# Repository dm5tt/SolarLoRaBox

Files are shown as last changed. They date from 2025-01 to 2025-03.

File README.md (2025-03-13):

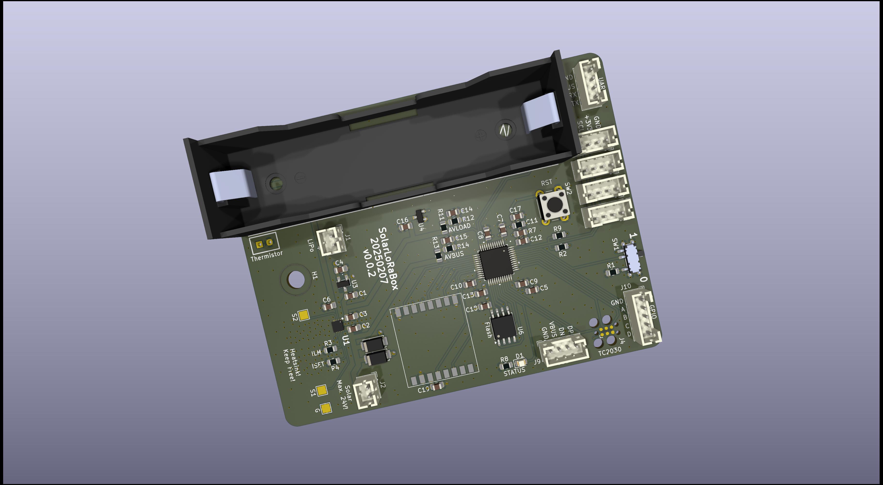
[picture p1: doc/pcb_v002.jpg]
SolarLoraBox PCB


# What is this thing?

This is an experimental platform for an solar driven LoRa sensor station based on the

- Microcontroller: ST STM32U083CCT6
- Radio: Heltec HT-RA62 (Semtech SX1262)
- Charging Controller: TI BQ25185
- Flash: Windbond W25Q128JVS (128 MBit)
- Reset IC: APX803L05-32SA-7 (3.2V)
- LDO: HEERMICR HE9073A30MR (3.0V)

Plan is to´ use it as platform for a wireless sensor based on Zephyr.

# Features

 - Solar Input up to 18V (24V survival)
 - 3A maximum load
 - 1A maximum charge current
 - Pseudo-MPPT (VINDPM)
 - Power Path (= if the battery is fully charged and there's enough solar power the device is getting powered directly from solar. It also can mix battery and solar energy.)
 - Two ADC signals for getting VLOAD and  VBUS voltage using voltage dividers
 - 3.7V LiPo either via 18650 block or JST-PH 2.0 connector

Lots if this stuff was already proven and validated in the project [SolarMeshtasticNode](https://github.com/dm5tt/SolarMeshtasticNode).

# Interfaces

- 4x I2C

- 1x UART

- 1x USB

- 1x GPIO with 4 available pins

# Programming interfaces

The STM32U0 spits out its bootloader on the I2C, UART and USB.

For "comfort programming" it has a TC2030 where you can connect a Segger or ST-Link

# Firmware

LoRa with Zephyr and TheThingsNetwork is already running :-)

Firmware integration tests are [here](https://github.com/dm5tt/SolarLoRaBox_Firmware)

# Evaluation

[Verification of PCB v0.0.1](EVALUATION-v001.md)

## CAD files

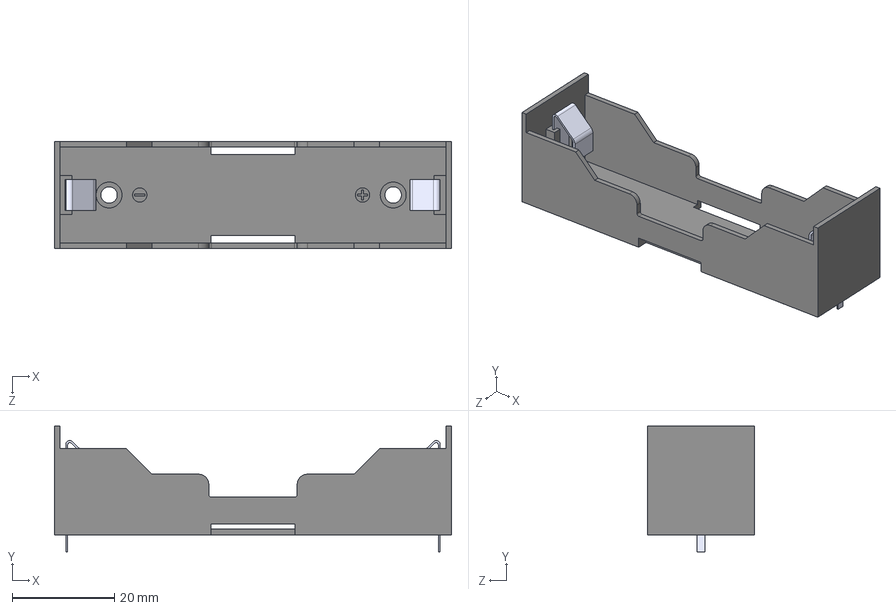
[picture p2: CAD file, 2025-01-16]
pcb/components/steps/BH-18650-PC.step
77.7 x 24.6 x 20.9 mm

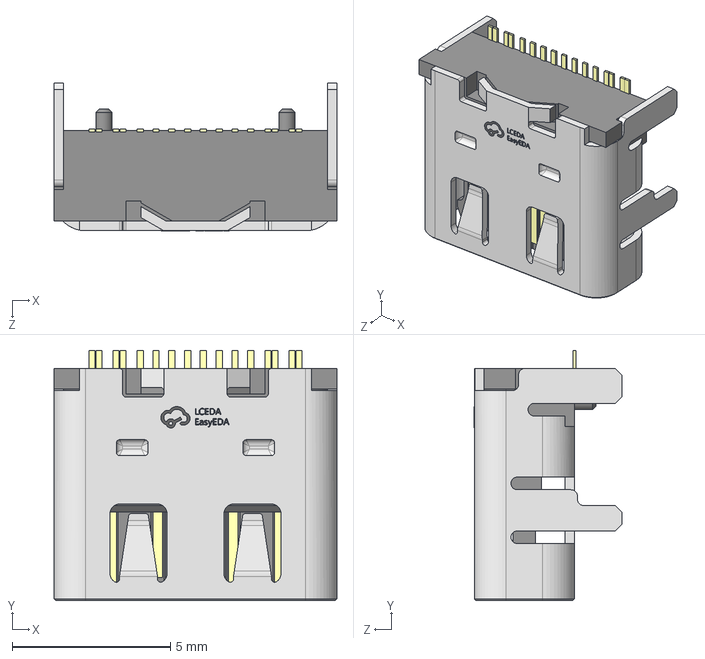
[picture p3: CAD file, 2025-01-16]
pcb/components/steps/USB-C-SMD_G-SWITCH_GT-USB-7010ASV.step
8.94 x 7.90 x 4.66 mm

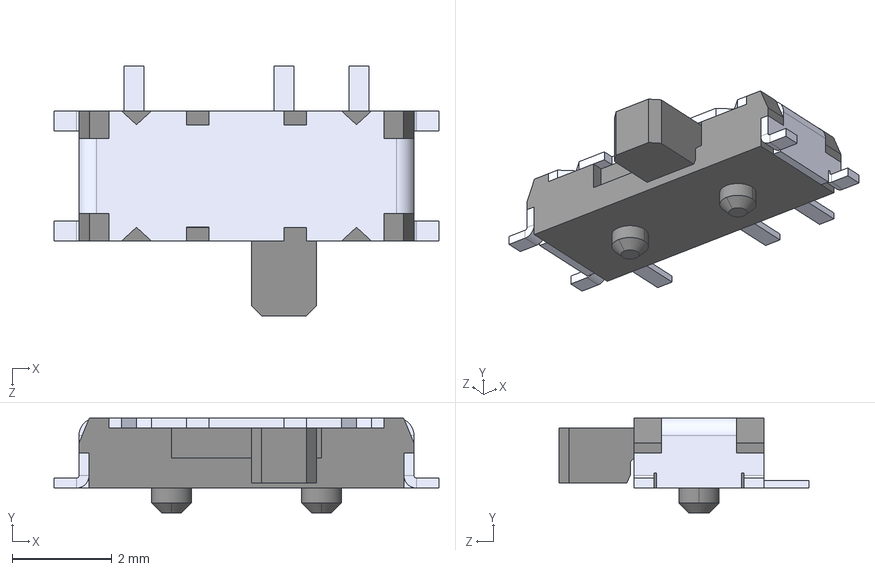
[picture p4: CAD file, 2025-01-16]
pcb/components/steps/SSSS811101--3DModel-STEP-269445.STEP
7.70 x 1.90 x 5.00 mm

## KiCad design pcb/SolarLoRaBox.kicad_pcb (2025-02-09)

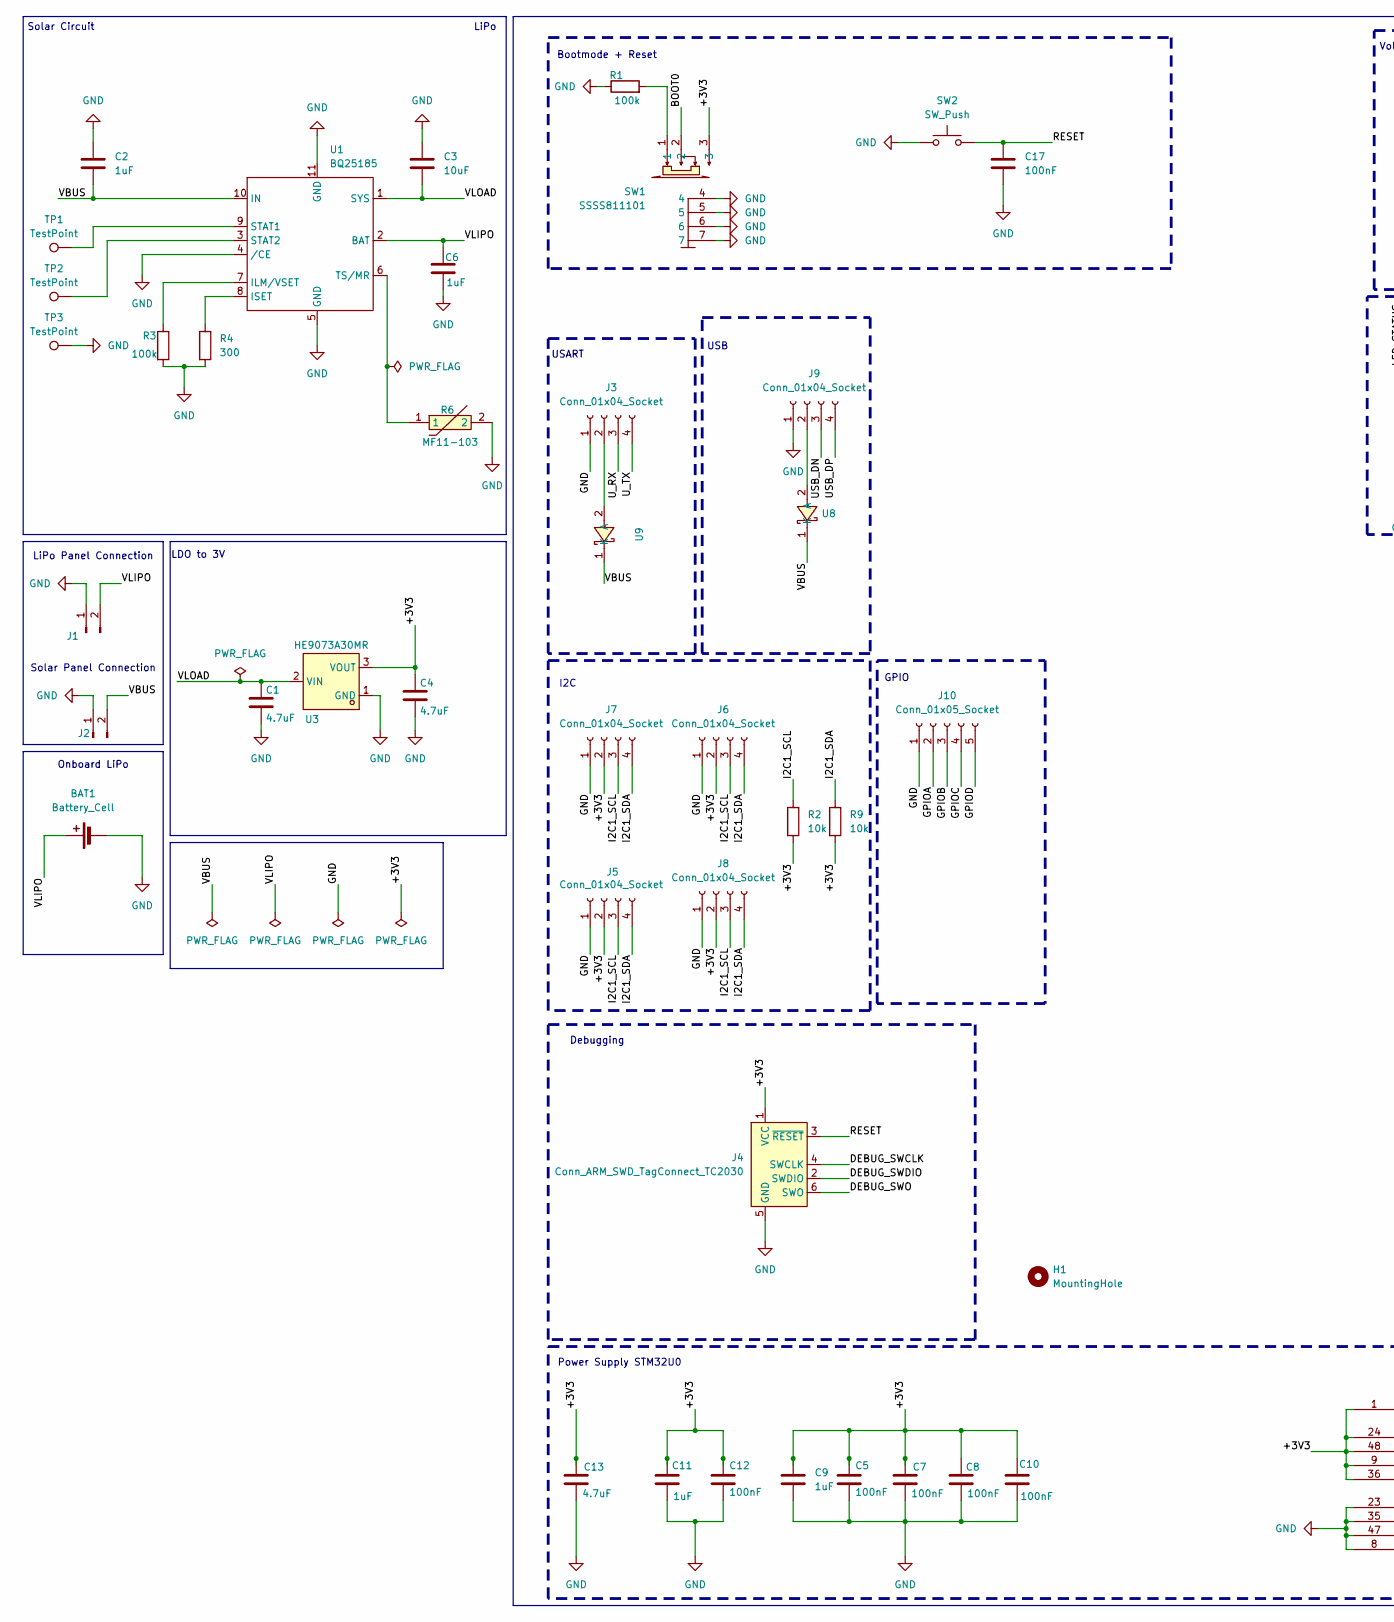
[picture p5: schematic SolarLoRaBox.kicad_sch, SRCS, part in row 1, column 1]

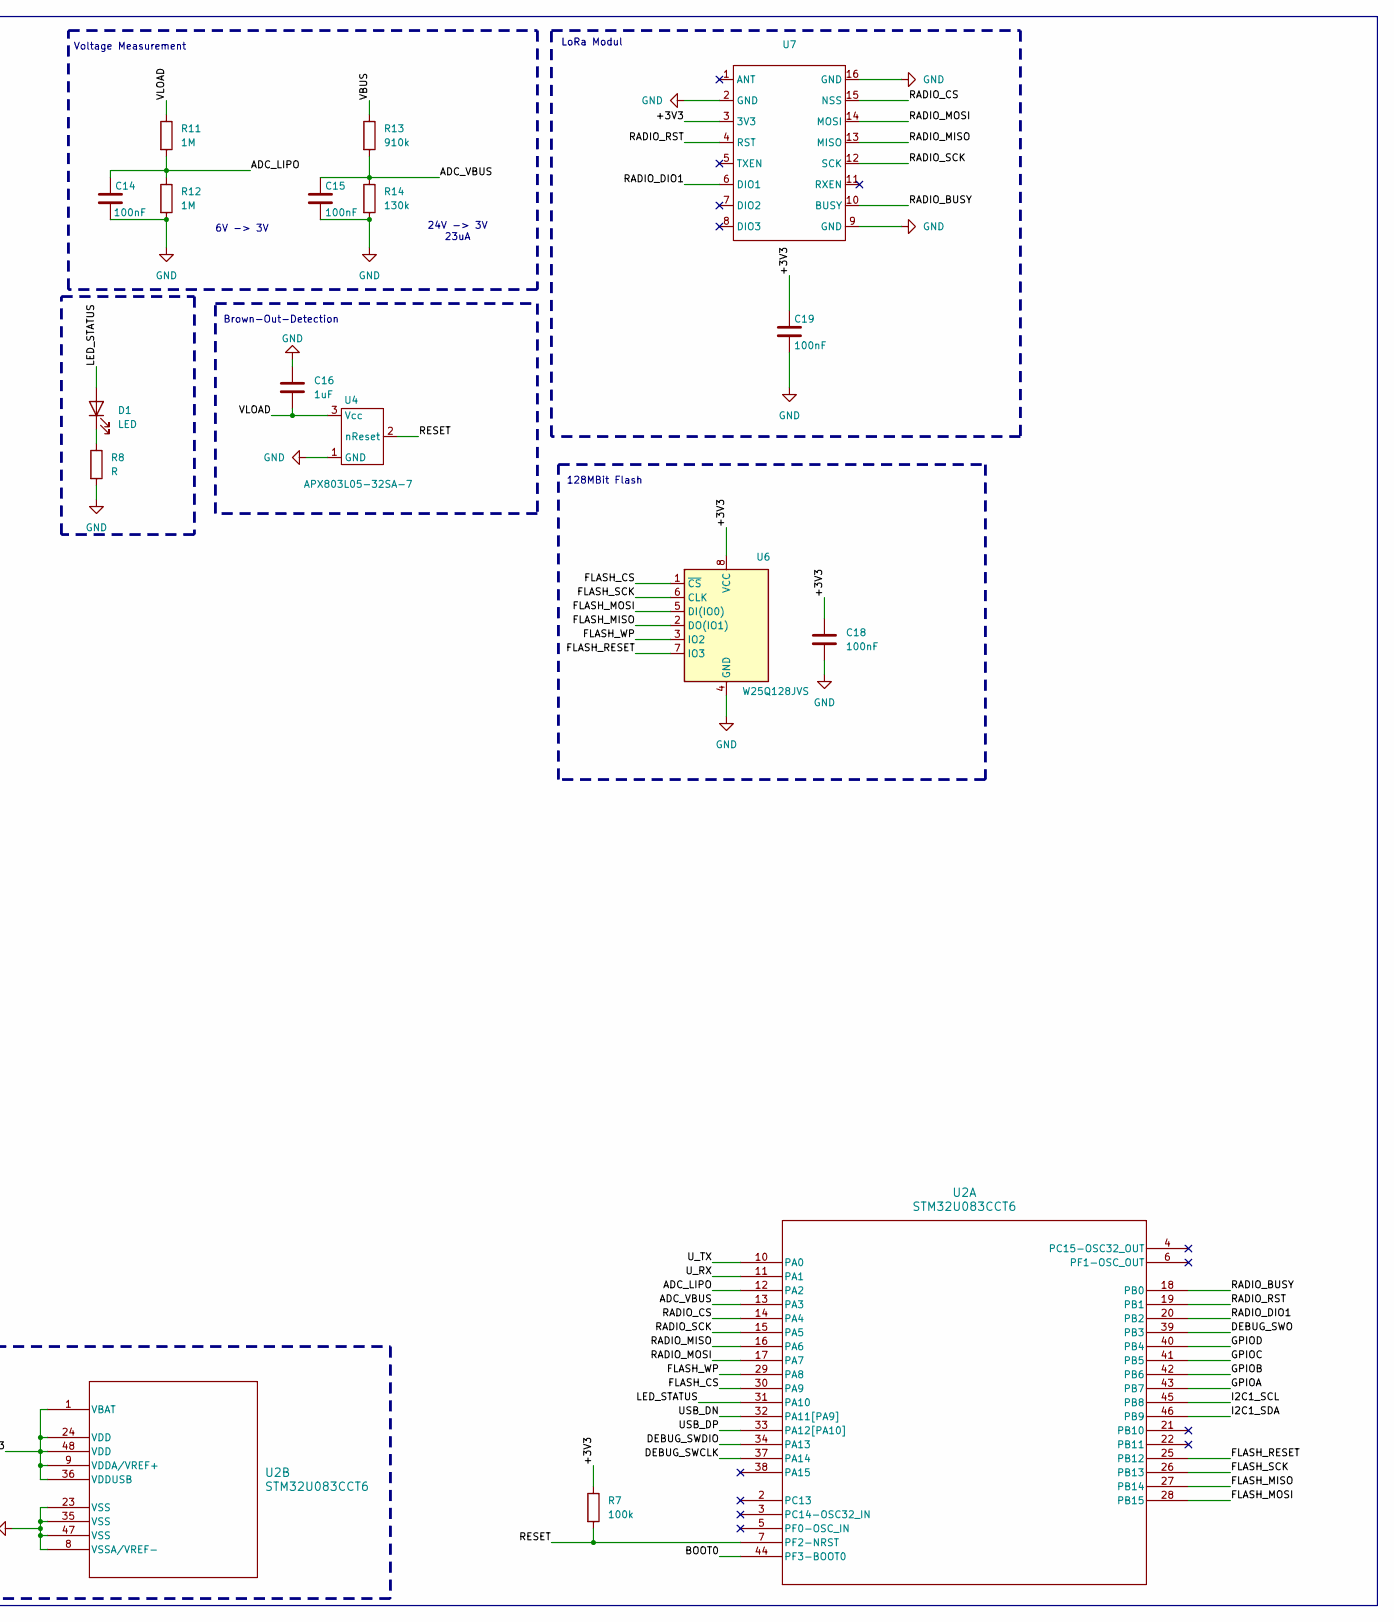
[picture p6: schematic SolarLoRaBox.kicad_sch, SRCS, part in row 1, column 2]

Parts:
BAT1: Battery_Cell; BAT-TH_BH-18650-A1AJ005
C1, C4, C13: 4.7uF; C_0805_2012Metric_Pad1.18x1.45mm_HandSolder
C2, C6, C9, C11, C16: 1uF; C_0805_2012Metric_Pad1.18x1.45mm_HandSolder
C3: 10uF; C_0805_2012Metric_Pad1.18x1.45mm_HandSolder
C5, C7, C8, C10, C12, C14, C15, C17, C18, C19: 100nF; C_0805_2012Metric_Pad1.18x1.45mm_HandSolder
D1: LED; LED_0805_2012Metric
H1: MountingHole; MountingHole_4.3mm_M4_DIN965
J1, J2: Conn_01x02_Socket; JST_PH_B2B-PH-K_1x02_P2.00mm_Vertical
J3, J5, J6, J7, J8, J9: Conn_01x04_Socket; JST_PH_B4B-PH-K_1x04_P2.00mm_Vertical
J4: Conn_ARM_SWD_TagConnect_TC2030; Tag-Connect_TC2030-IDC-FP_2x03_P1.27mm_Vertical
J10: Conn_01x05_Socket; JST_PH_B5B-PH-K_1x05_P2.00mm_Vertical
R1, R3, R7: 100k; R_0805_2012Metric_Pad1.20x1.40mm_HandSolder
R2, R9: 10k; R_0805_2012Metric_Pad1.20x1.40mm_HandSolder
R4: 300; R_0805_2012Metric_Pad1.20x1.40mm_HandSolder
R6: MF11-103; RES-TH_L6.5-W4.0-P2.50-D0.5; LCSC Part C70913
R8: R; R_0805_2012Metric_Pad1.20x1.40mm_HandSolder
R11, R12: 1M; R_0805_2012Metric_Pad1.20x1.40mm_HandSolder
R13: 910k; R_0805_2012Metric_Pad1.20x1.40mm_HandSolder
R14: 130k; R_0805_2012Metric_Pad1.20x1.40mm_HandSolder
SW1: SSSS811101; SW-SMD_SSSS811101; LCSC Part C109335
SW2: SW_Push; SW_PUSH_6mm
TP1, TP2, TP3: TestPoint; TestPoint_Pad_2.0x2.0mm
U1: BQ25185; SON40P220X200X80-11N
U2: STM32U083CCT6; LQFP48_STM
U3: HE9073A30MR; SOT-23-3_L2.9-W1.6-P1.90-LS2.8-BR-CW; LCSC Part C723793
U4: APX803L05-32SA-7; SOT23-3
U6: W25Q128JVS; SOIC-8_5.23x5.23mm_P1.27mm
U7: HT-RA62
U8, U9: SS26_C5350986; SMA_L4.3-W2.6-LS5.1-RD; LCSC Part C5350986

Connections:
/+3V3: C4.1, C5.1, C7.1, C8.1, C9.1, C10.1, C11.1, C12.1, C13.1, C18.1, C19.1, J4.1 (VCC), J5.2, J6.2, J7.2, J8.2, R2.2, R7.1, R9.2, SW1.3, U2.1 (VBAT), U2.9 (VDDA/VREF+), U2.24 (VDD), U2.36 (VDDUSB), U2.48 (VDD), U3.3 (VOUT), U6.8 (VCC), U7.3 (3V3)
/ADC_LIPO: C14.1, R11.2, R12.1, U2.12 (PA2)
/ADC_VBUS: C15.1, R13.2, R14.1, U2.13 (PA3)
/BOOT0: SW1.2, U2.44 (PF3-BOOT0)
/DEBUG_SWCLK: J4.4 (SWCLK), U2.37 (PA14)
/DEBUG_SWDIO: J4.2 (SWDIO), U2.34 (PA13)
/DEBUG_SWO: J4.6 (SWO), U2.39 (PB3)
/FLASH_CS: U2.30 (PA9), U6.1 (~CS)
/FLASH_MISO: U2.27 (PB14), U6.2 (DO(IO1))
/FLASH_MOSI: U2.28 (PB15), U6.5 (DI(IO0))
/FLASH_RESET: U2.25 (PB12), U6.7 (IO3)
/FLASH_SCK: U2.26 (PB13), U6.6 (CLK)
/FLASH_WP: U2.29 (PA8), U6.3 (IO2)
/GPIOA: J10.2, U2.43 (PB7)
/GPIOB: J10.3, U2.42 (PB6)
/GPIOC: J10.4, U2.41 (PB5)
/GPIOD: J10.5, U2.40 (PB4)
/I2C1_SCL: J5.3, J6.3, J7.3, J8.3, R2.1, U2.45 (PB8)
/I2C1_SDA: J5.4, J6.4, J7.4, J8.4, R9.1, U2.46 (PB9)
/LED_STATUS: D1.2 (A), U2.31 (PA10)
/RADIO_BUSY: U2.18 (PB0), U7.10 (BUSY)
/RADIO_CS: U2.14 (PA4), U7.15 (NSS)
/RADIO_DIO1: U2.20 (PB2), U7.6 (DIO1)
/RADIO_MISO: U2.16 (PA6), U7.13 (MISO)
/RADIO_MOSI: U2.17 (PA7), U7.14 (MOSI)
/RADIO_RST: U2.19 (PB1), U7.4 (RST)
/RADIO_SCK: U2.15 (PA5), U7.12 (SCK)
/RESET: C17.1, J4.3 (~RESET), R7.2, SW2.2, U2.7 (PF2-NRST), U4.2 (nReset)
/USB_DN: J9.3, U2.32 (PA11[PA9])
/USB_DP: J9.4, U2.33 (PA12[PA10])
/U_RX: J3.3, U2.11 (PA1)
/U_TX: J3.4, U2.10 (PA0)
/VBUS: C2.2, J2.2, R13.1, U1.10 (IN), U8.1 (K), U9.1 (K)
/VLIPO: BAT1.1 (+), C6.1, J1.2, U1.2 (BAT)
/VLOAD: C1.1, C3.2, C16.2, R11.1, U1.1 (SYS), U3.2 (VIN), U4.3 (Vcc)
GND: BAT1.2 (-), C1.2, C2.1, C3.1, C4.2, C5.2, C6.2, C7.2, C8.2, C9.2, C10.2, C11.2, C12.2, C13.2, C14.2, C15.2, C16.1, C17.2, C18.2, C19.2, J1.1, J2.1, J3.1, J4.5 (GND), J5.1, J6.1, J7.1, J8.1, J9.1, J10.1, R1.1, R3.2, R4.2, R6.2, R8.2, R12.2, R14.2, SW1.4, SW1.5, SW1.6, SW1.7, SW2.1, TP3.1, U1.4 (/CE), U1.5 (GND), U1.11 (GND), U2.8 (VSSA/VREF-), U2.23 (VSS), U2.35 (VSS), U2.47 (VSS), U3.1 (GND), U4.1 (GND), U6.4 (GND), U7.2 (GND), U7.9 (GND), U7.16 (GND)
unnamed: D1.1 (K), R8.1
unnamed: J3.2, U9.2 (A)
unnamed: J9.2, U8.2 (A)
unnamed: R1.2, SW1.1
unnamed: R3.1, U1.7 (ILM/VSET)
unnamed: R4.1, U1.8 (ISET)
unnamed: TP1.1, U1.9 (STAT1)
unnamed: TP2.1, U1.3 (STAT2)
unnamed: R6.1, U1.6 (TS/MR)

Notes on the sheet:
Solar Circuit
Bootmode + Reset
Power Supply STM32U0
6V -> 3V
USART
Voltage Measurement
Debugging
LiPo
LiPo Panel Connection
USB
GPIO
Brown-Out-Detection
Onboard LiPo
Solar Panel Connection
LDO to 3V
I2C
128MBit Flash
LoRa Modul
24V -> 3V 23uA

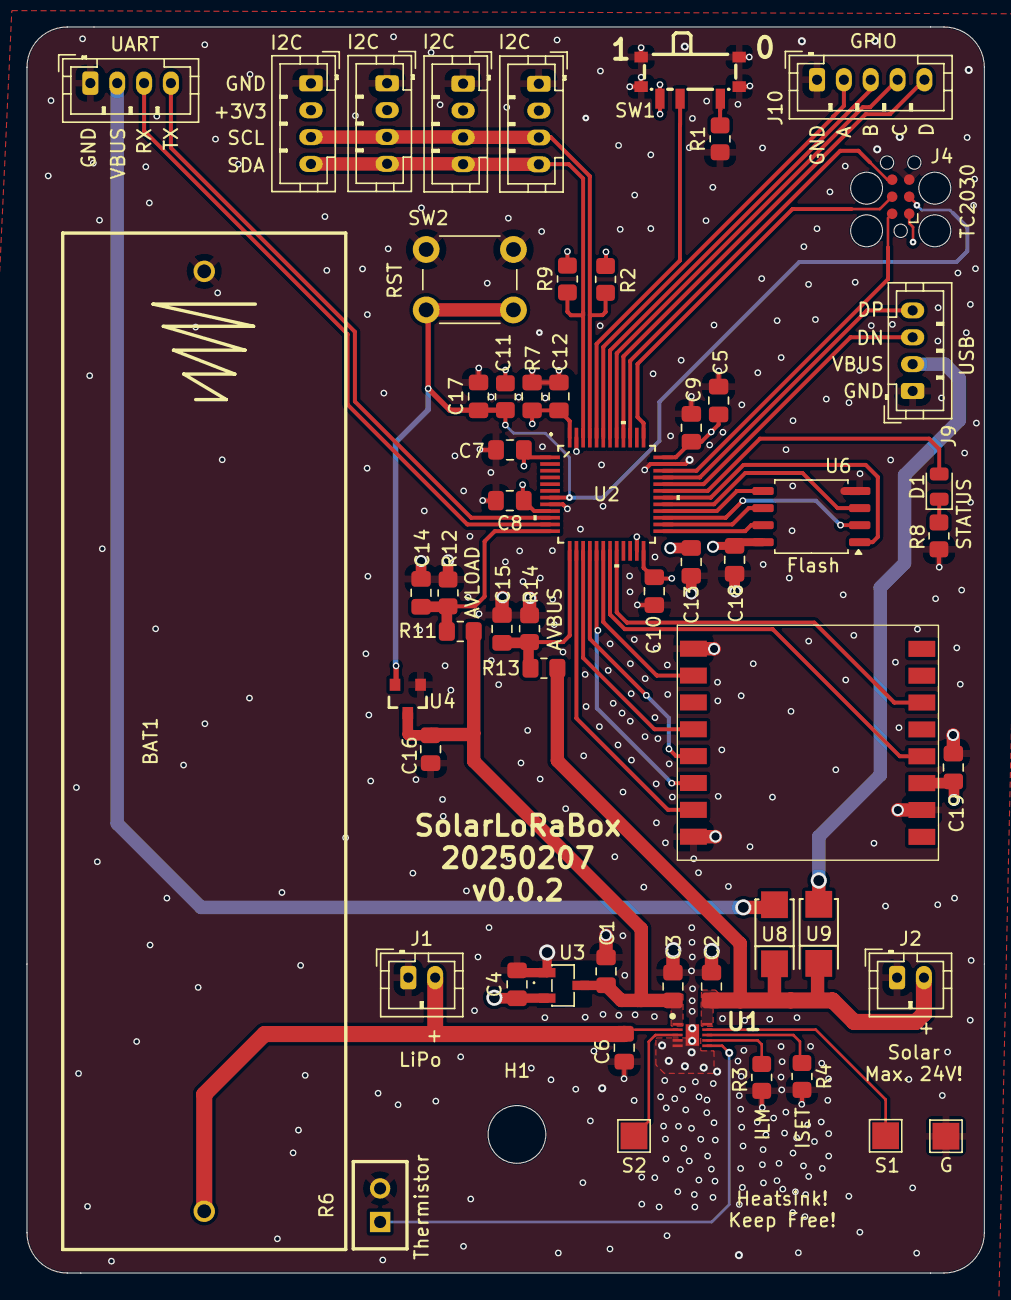
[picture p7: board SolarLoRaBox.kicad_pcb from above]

Board: 4 copper layers, 71.3 x 92.8 mm, 57 parts (0 on the bottom side), 45 nets.

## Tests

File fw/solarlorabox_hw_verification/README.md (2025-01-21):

# What is this thing?

This is a STM32CubeIDE 1.17.0 project to verify all hardware components:

 - SPI Flash
 - SPI LoRa
 - ADC
 - Serial Port
 - USB
 - SWD

 It's ugly. But not worth spending more time here.

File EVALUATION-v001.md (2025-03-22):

# Hardware verification (v0.0.1)

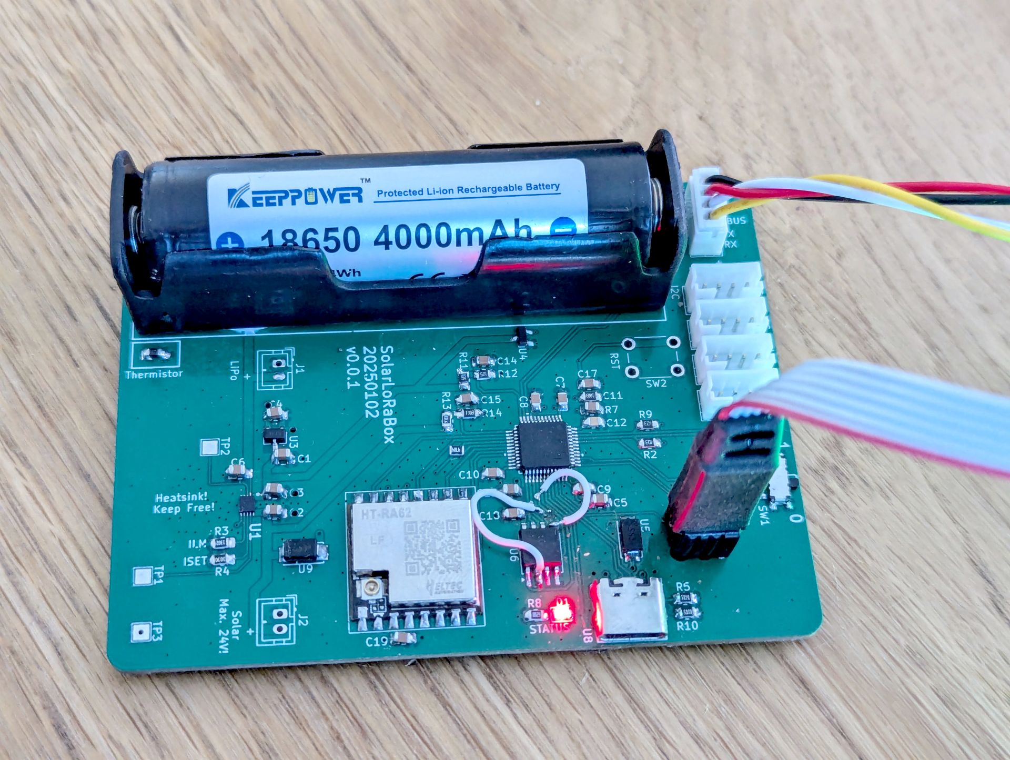
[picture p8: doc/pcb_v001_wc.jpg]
Drag Racing


### SWD interface: ✅

```
 - Connecting via USB to probe/ programmer device 0
 - Probe/ Programmer firmware: x
 - Probe/ Programmer S/N: x
 - Device "STM32U083CC" selected.
 - Target interface speed: 4000 kHz (Fixed)
 - VTarget = 3.324V
 - InitTarget() start
 - InitTarget() end - Took 33.1ms
 - Found SW-DP with ID 0x6BA02477
 - DPIDR: 0x6BA02477
 - CoreSight SoC-400 or earlier
 - Scanning AP map to find all available APs
 - AP[2]: Stopped AP scan as end of AP map has been reached
 - AP[0]: AHB-AP (IDR: 0x84770001, ADDR: 0x00000000)
 - AP[1]: APB-AP (IDR: 0x54770002, ADDR: 0x01000000)
 - Iterating through AP map to find AHB-AP to use
 - AP[0]: Core found
 - AP[0]: AHB-AP ROM base: 0xF0000000
 - CPUID register: 0x410CC601. Implementer code: 0x41 (ARM)
 - Found Cortex-M0 r0p1, Little endian.
 - FPUnit: 4 code (BP) slots and 0 literal slots
 - CoreSight components:
 - ROMTbl[0] @ F0000000
 - [0][0]: E00FF000 CID B105100D PID 000BB4C0 ROM Table
 - ROMTbl[1] @ E00FF000
 - [1][0]: E000E000 CID B105E00D PID 000BB008 SCS
 - [1][1]: E0001000 CID B105E00D PID 000BB00A DWT
 - [1][2]: E0002000 CID B105E00D PID 000BB00B FPB
 - Executing init sequence ...
  - Initialized successfully
 - Target interface speed: 4000 kHz (Fixed)
 - Found 1 JTAG device. Core ID: 0x6BA02477 (None)
 - Connected successfully
```

### Bootloader mode (USB): ✅

Switch set to "0"

```
Found DFU: [0483:df11] ver=0220, devnum=13, cfg=1, intf=0, path="3-3.3", alt=3, name="@ENGI Bytes        /0x1FFF6C00/01*1024.e", serial="x"
Found DFU: [0483:df11] ver=0220, devnum=13, cfg=1, intf=0, path="3-3.3", alt=2, name="@OTP Memory        /0x1FFF6800/01*1024 e", serial="x"
Found DFU: [0483:df11] ver=0220, devnum=13, cfg=1, intf=0, path="3-3.3", alt=1, name="@OB Bytes          /0x40022020/01*136 e", serial="x"
Found DFU: [0483:df11] ver=0220, devnum=13, cfg=1, intf=0, path="3-3.3", alt=0, name="@Internal Flash    /0x08000000/128*02Kg", serial="x"
```

### USB: ⚠️

That USB-C connector is useless in a box.

Replace with a JST connector as 12MBit/s USB isn't critical in terms of impedance matching. 

### LED: ✅

Blinks.

### UART: ⚠️

Mixed up Silk print. RX/TX text must be swapped.

### SPI, Flash: 🚨

MOSI -> DI

MISO -> DO

Whoever did this..  that's not the usual convention how you name things on a SPI bus.

If switched it works.

```
/* 0x90 = Read Device ID
 * 0x00 0x00 0x00 = Dummy Address
*/
uint8_t request[4] = { 0x90, 0x00, 0x00, 0x00 };

uint8_t response[2] = { 0 };

HAL_GPIO_WritePin(GPIOA, FLASH_CS_Pin, GPIO_PIN_RESET);
HAL_SPI_Transmit(&hspi2, request, sizeof(request), HAL_MAX_DELAY);
HAL_SPI_Receive(&hspi2, response, sizeof(response), HAL_MAX_DELAY);
HAL_GPIO_WritePin(GPIOA, FLASH_CS_Pin, GPIO_PIN_SET);
```

Results in

```
response[0]	uint8_t	0xef (Hex)	
response[1]	uint8_t	0x17 (Hex)	
```

Which is the same specified in the datasheet.

### SPI, LoRa: ✅

```
	/* 0x1d = Read one or several registers
	 * 0x0320 = Product ID String
	 */
	uint8_t request[4] = { 0x1D, 0x03, 0x20 };
	uint8_t response[16] = { 0 };

	/* Infinite loop */
	for (;;) {
		osDelay(1000);

		HAL_GPIO_WritePin(GPIOA, RADIO_CS_Pin, GPIO_PIN_RESET);

		HAL_SPI_Transmit(&hspi1, request, sizeof(request), HAL_MAX_DELAY);
		HAL_SPI_Receive(&hspi1, response, sizeof(response), HAL_MAX_DELAY);

		HAL_GPIO_WritePin(GPIOA, RADIO_CS_Pin, GPIO_PIN_SET);

		printf("LoRa Product ID: %s\r\n", response);

	}

```

Results in

```
LoRa Product ID: SX1261 V2D 2D02
```

### ADC: ✅

```
Channel 6 Input Voltage: 4.699 V
Channel 7 Input Voltage: 1.368 V
```

### Reset IC: ⚠️

Needs a buffer capacitor in front of  the sensing line. 

[This caused problems with the SolarMeshtasticBox.](https://github.com/dm5tt/SolarMeshtasticNode/issues/3)

### Run Test ✅



No power saving implemented - just a naked Zephyr that pushes the battery voltage to the TheThingsNetwork.

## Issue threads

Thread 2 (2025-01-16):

Replace USB connector with 4-pin JST

dm5tt, 2025-01-16:

dm5tt, 2025-01-16:
That thing is basically useless in a box.

dm5tt, 2025-01-19:
Fixed with v0.0.2.

Closed 2025-01-19.

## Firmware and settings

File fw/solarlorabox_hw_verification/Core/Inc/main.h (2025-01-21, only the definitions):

#define ADC_LIPO_Pin GPIO_PIN_2
#define ADC_LIPO_GPIO_Port GPIOA
#define ADC_VBUS_Pin GPIO_PIN_3
#define ADC_VBUS_GPIO_Port GPIOA
#define RADIO_CS_Pin GPIO_PIN_4
#define RADIO_CS_GPIO_Port GPIOA
#define RADIO_SCK_Pin GPIO_PIN_5
#define RADIO_SCK_GPIO_Port GPIOA
#define RADIO_MISO_Pin GPIO_PIN_6
#define RADIO_MISO_GPIO_Port GPIOA
#define RADIO_MOSI_Pin GPIO_PIN_7
#define RADIO_MOSI_GPIO_Port GPIOA
#define RADIO_BUSY_Pin GPIO_PIN_0
#define RADIO_BUSY_GPIO_Port GPIOB
#define RADIOR_RST_Pin GPIO_PIN_1
#define RADIOR_RST_GPIO_Port GPIOB
#define RADIO_DIO1_Pin GPIO_PIN_2
#define RADIO_DIO1_GPIO_Port GPIOB
#define FLASH_RESET_Pin GPIO_PIN_12
#define FLASH_RESET_GPIO_Port GPIOB
#define FLASH_SCK_Pin GPIO_PIN_13
#define FLASH_SCK_GPIO_Port GPIOB
#define FLASH_MISO_Pin GPIO_PIN_14
#define FLASH_MISO_GPIO_Port GPIOB
#define FLASH_MOSI_Pin GPIO_PIN_15
#define FLASH_MOSI_GPIO_Port GPIOB
#define FLASH_WP_Pin GPIO_PIN_8
#define FLASH_WP_GPIO_Port GPIOA
#define FLASH_CS_Pin GPIO_PIN_9
#define FLASH_CS_GPIO_Port GPIOA
#define LED_STATUS_Pin GPIO_PIN_10
#define LED_STATUS_GPIO_Port GPIOA

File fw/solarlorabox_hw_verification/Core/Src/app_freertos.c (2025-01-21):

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

/* Includes ------------------------------------------------------------------*/
#include "app_freertos.h"

/* USER CODE BEGIN Includes */
#include "task_usart.h"
#include "task_flash.h"
#include "task_lora.h"
#include "task_adc.h"
/* USER CODE END Includes */

/* Definitions for defaultTask */
osThreadId_t defaultTaskHandle;
const osThreadAttr_t defaultTask_attributes = {
  .name = "defaultTask",
  .priority = (osPriority_t) osPriorityNormal,
  .stack_size = 128 * 4
};

/* USER CODE BEGIN FunctionPrototypes */
osThreadId_t task_usart_handle;
const osThreadAttr_t task_usart_attributes = {
  .name = "task_usart",
  .priority = (osPriority_t) osPriorityNormal,
  .stack_size = 128 * 4
};

osThreadId_t task_flash_handle;
const osThreadAttr_t task_flash_attributes = {
  .name = "task_flash",
  .priority = (osPriority_t) osPriorityNormal,
  .stack_size = 128 * 4
};

osThreadId_t task_lora_handle;
const osThreadAttr_t task_lora_attributes = {
  .name = "task_lora",
  .priority = (osPriority_t) osPriorityNormal,
  .stack_size = 128 * 4
};

osThreadId_t task_adc_handle;
const osThreadAttr_t task_adc_attributes = {
  .name = "task_adc",
  .priority = (osPriority_t) osPriorityNormal,
  .stack_size = 128 * 10
};
/* USER CODE END FunctionPrototypes */

/**
  * @brief  FreeRTOS initialization
  * @param  None
  * @retval None
  */
void MX_FREERTOS_Init(void) {
  /* USER CODE BEGIN RTOS_MUTEX */
  /* add mutexes, ... */
  /* USER CODE END RTOS_MUTEX */

  /* USER CODE BEGIN RTOS_SEMAPHORES */
  /* add semaphores, ... */
  /* USER CODE END RTOS_SEMAPHORES */

  /* USER CODE BEGIN RTOS_TIMERS */
  /* start timers, add new ones, ... */
  /* USER CODE END RTOS_TIMERS */

  /* USER CODE BEGIN RTOS_QUEUES */
  /* add queues, ... */
  /* USER CODE END RTOS_QUEUES */
  /* creation of defaultTask */
  defaultTaskHandle = osThreadNew(StartDefaultTask, NULL, &defaultTask_attributes);

  /* USER CODE BEGIN RTOS_THREADS */
  task_usart_handle = osThreadNew(task_usart, NULL, &task_usart_attributes);
  task_flash_handle = osThreadNew(task_flash, NULL, &task_flash_attributes);
  task_lora_handle = osThreadNew(task_lora, NULL, &task_lora_attributes);
  task_adc_handle = osThreadNew(task_adc, NULL, &task_adc_attributes);
  /* USER CODE END RTOS_THREADS */

  /* USER CODE BEGIN RTOS_EVENTS */
  /* add events, ... */
  /* USER CODE END RTOS_EVENTS */

}
/* USER CODE BEGIN Header_StartDefaultTask */
/**
* @brief Function implementing the defaultTask thread.
* @param argument: Not used
* @retval None
*/
/* USER CODE END Header_StartDefaultTask */
void StartDefaultTask(void *argument)
{
  /* USER CODE BEGIN defaultTask */
  /* Infinite loop */
  for(;;)
  {
	HAL_GPIO_WritePin(GPIOA, LED_STATUS_Pin, GPIO_PIN_RESET);
    osDelay(1000);
    HAL_GPIO_WritePin(GPIOA, LED_STATUS_Pin, GPIO_PIN_SET);
    osDelay(1000);
  }
  /* USER CODE END defaultTask */
}



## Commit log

2025-01-16 pcb: rework heatsink area below the solar charging controller
    [SolarLoRaBox.kicad_pcb]
2025-01-17 pcb, sch: fix invalid uart rx/tx silk print, add C infront of reset ic
    [SolarLoRaBox.kicad_pcb, SolarLoRaBox.kicad_sch]
2025-01-17 Updates pictures and reorganize structure a bit
    [SolarLoRaBox.kicad_pcb]
2025-01-17 pcb, sch, doc: lots of cosmetic fixes
    [SolarLoRaBox.kicad_pcb, SolarLoRaBox.kicad_sch]
2025-01-17 pcb, sch: more eyecandy
    [SolarLoRaBox.kicad_pcb]
2025-01-21 EVALUATION-v001: add LED
2025-01-21 pcb, sch: switch MISO/MOSI on Windbond flash as they are inverted!
    [SolarLoRaBox.kicad_pcb, SolarLoRaBox.kicad_sch]
2025-01-21 EVALUATION-v001: SPI for the flash
2025-01-21 EVALUATION: ADC verified
    [SolarLoRaBox.kicad_pcb, SolarLoRaBox.kicad_sch]
2025-01-21 pcb, sch: match silk print and schematic
    [SolarLoRaBox.kicad_pcb, SolarLoRaBox.kicad_sch]
2025-02-09 pcb: non functional changes
    [SolarLoRaBox.kicad_pcb]

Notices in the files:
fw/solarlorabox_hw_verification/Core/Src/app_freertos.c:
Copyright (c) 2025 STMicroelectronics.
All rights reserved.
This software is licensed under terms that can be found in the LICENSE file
